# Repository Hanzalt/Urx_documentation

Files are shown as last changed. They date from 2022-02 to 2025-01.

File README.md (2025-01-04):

# Urx_documentation
Welcome to the Urx_documentation! You may be wondering what URX is. URX is first completely open source console. This means that if you want to, you can create it by yourself and completly for FREE. The case is printed on a 3D printer. Electrical components are imported from China and from GM electronics.

To find out more, go to the wiki!

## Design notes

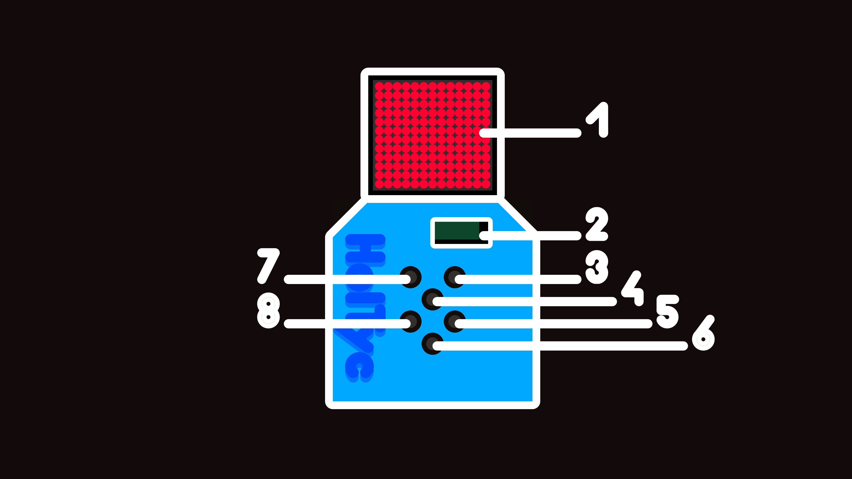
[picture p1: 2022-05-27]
wiki_images/shora.jpg

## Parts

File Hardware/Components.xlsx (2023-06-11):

Komponenty | URL | Poznámka
baterie - 3450 | https://www.gme.cz/akumulator-lithiovy-panasonic-ncr-18650ga-3450 | variace/ lepší baterka
baterie - 2600 | https://www.gme.cz/akumulator-lithiovy-westinghouse-li-ion-18650-2600mah | .
piezo pipac | https://www.gme.cz/kpe-110 | .
arduino nano every | https://store.arduino.cc/products/arduino-nano-every-pack?variant=40830133698711 | .
oled 0,91 inch | https://www.aliexpress.com/item/32798439084.html?spm=a2g0o.order_list.0.0.21ef1802zovYiK | .
zapínací tlačítko | https://www.aliexpress.com/item/4000834984463.html?spm=a2g0o.order_list.0.0.21ef1802vfbqA9 | .
tlačítka | https://www.aliexpress.com/item/33002039235.html?spm=a2g0o.order_list.0.0.21ef1802vfbqA9 | .
nabíjecí modul | https://www.aliexpress.com/item/4001196670805.html?spm=a2g0o.order_list.0.0.21ef1802vfbqA9 | .
display 16x16 | https://www.aliexpress.com/item/1005001288031779.html | .
boost converter | https://www.aliexpress.com/item/4001101711737.html?spm=a2g0o.order_list.0.0.21ef1802zovYiK | .
jst-ph-10-kabely - oboustrana koncovka (bude pouzito) | https://www.aliexpress.com/item/32859226460.html?srcSns=sns_More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 | .
jst-ph-10-kabely - koncovky | https://www.aliexpress.com/item/1005003999865632.html?srcSns=sns_More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 | .
jst-ph-10,5,4-pin | https://www.aliexpress.com/item/4000091077742.html | .
piny - male | https://www.aliexpress.com/item/32724478308.html?spm=a2g0o.order_list.0.0.21ef18029P73HY | .
piny - female Arduino | https://www.aliexpress.com/item/32962790286.html?spm=a2g0o.order_list.0.0.21ef18029P73HY | .
matičky | https://www.sroubyonline.cz/standardni-matice-ocel-bily-zinek-6-din-934 | M3
šroubky | https://www.sroubyonline.cz/spojovaci-material/srouby/zapustne-srouby/din-965-ocel-zinek-bily | M3x8
pcb tlačítka | https://jlcpcb.com/ | .
pcb URX | https://jlcpcb.com/ | .
krabice male | https://www.top-obaly.cz/produkt/kartonove-krabice-postovni#product-199x121x45mm | .
krabice velke | https://www.top-obaly.cz/produkt/kartonove-krabice-postovni#product-235x185x46mm | .
Flo-pak | https://www.top-obaly.cz/produkt/vyplnovy-material-flo-pak#product-green-1 | .
ZIP sáček | https://www.top-obaly.cz/produkt/zip-sacky-classic#product-40x60mm

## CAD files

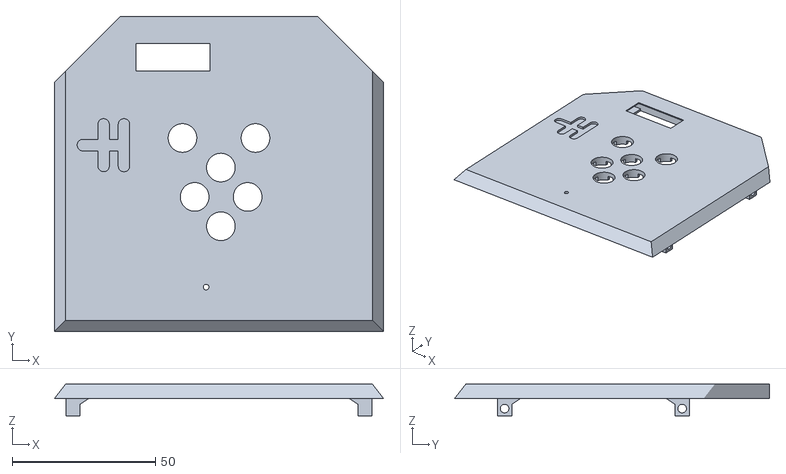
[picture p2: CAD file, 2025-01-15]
Models/Urx_1_top_v4.stl
115.0 x 110.0 x 11.0

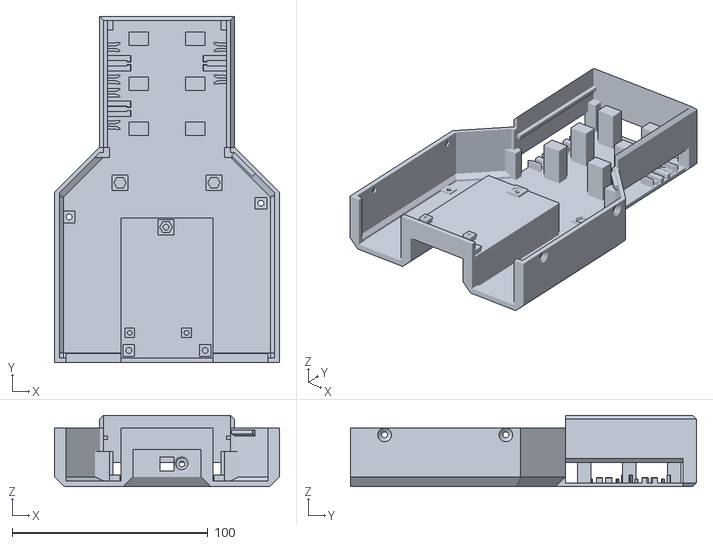
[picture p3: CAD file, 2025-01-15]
Models/Urx_1_bot_v4.stl
115.0 x 177.0 x 36.5

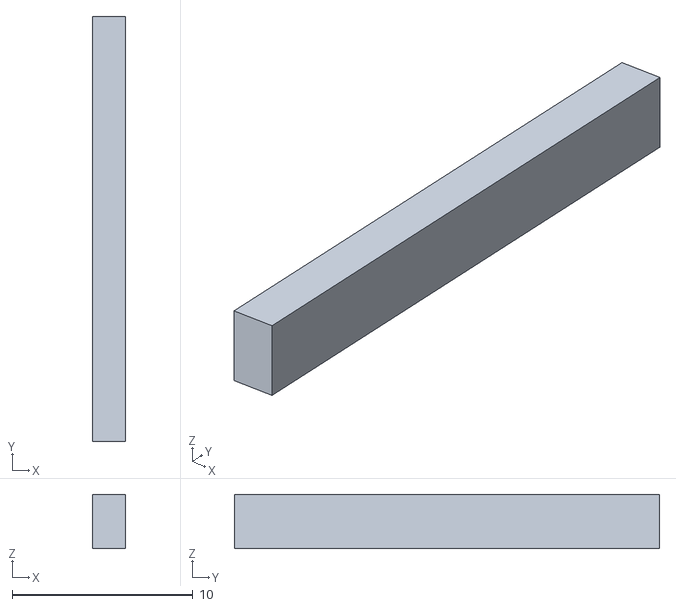
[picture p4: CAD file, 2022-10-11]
Models/Urx_1_tablet_v1.stl
1.80 x 23.5 x 3.00

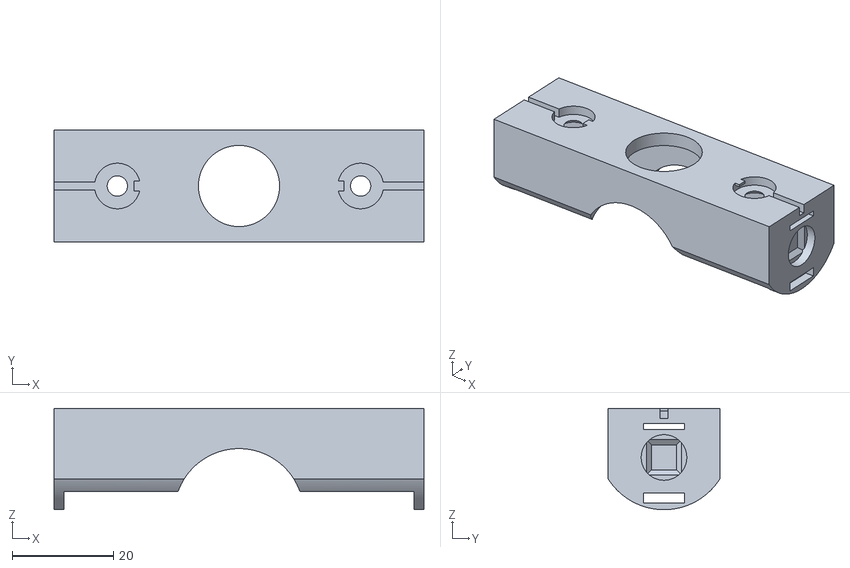
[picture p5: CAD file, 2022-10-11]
Models/Urx_1_battery_holder_v2.stl
73.0 x 22.0 x 20.0

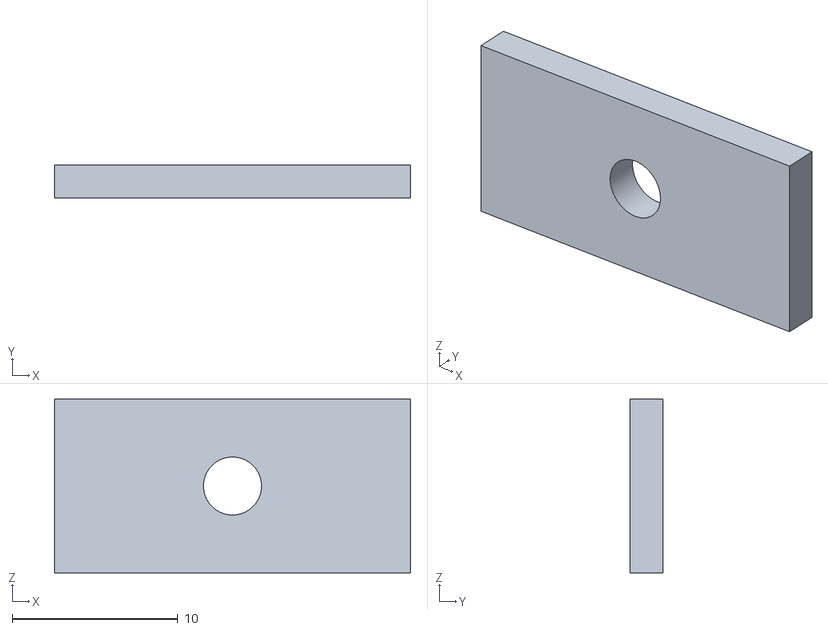
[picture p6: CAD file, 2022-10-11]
Models/Urx_1_power_button_tablet_v1.stl
21.5 x 2.00 x 10.5

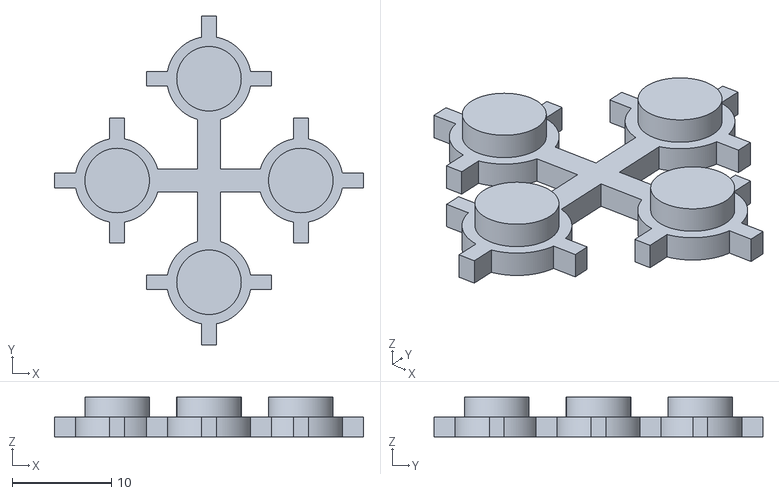
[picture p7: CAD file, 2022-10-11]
Models/Urx_1_buttons_flex_spider_v1.stl
31.1 x 33.1 x 4.00

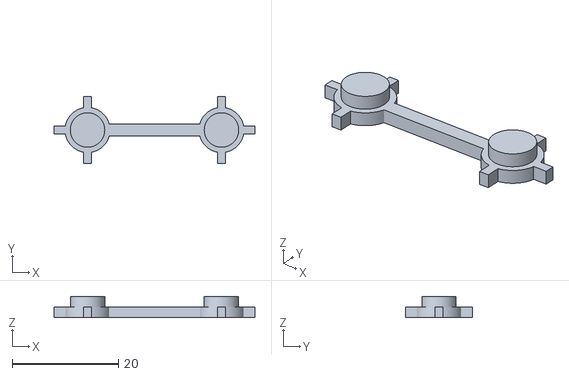
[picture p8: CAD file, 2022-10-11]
Models/Urx_1_buttons_flex_v1.stl
37.9 x 12.6 x 4.00

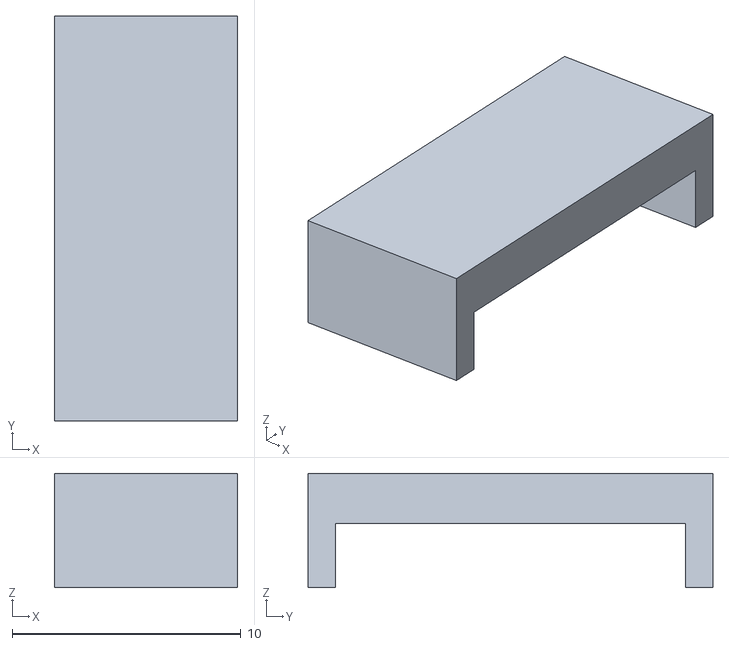
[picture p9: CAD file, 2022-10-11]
Models/Urx_1_secure_tablet_v1.stl
8.00 x 17.7 x 5.00

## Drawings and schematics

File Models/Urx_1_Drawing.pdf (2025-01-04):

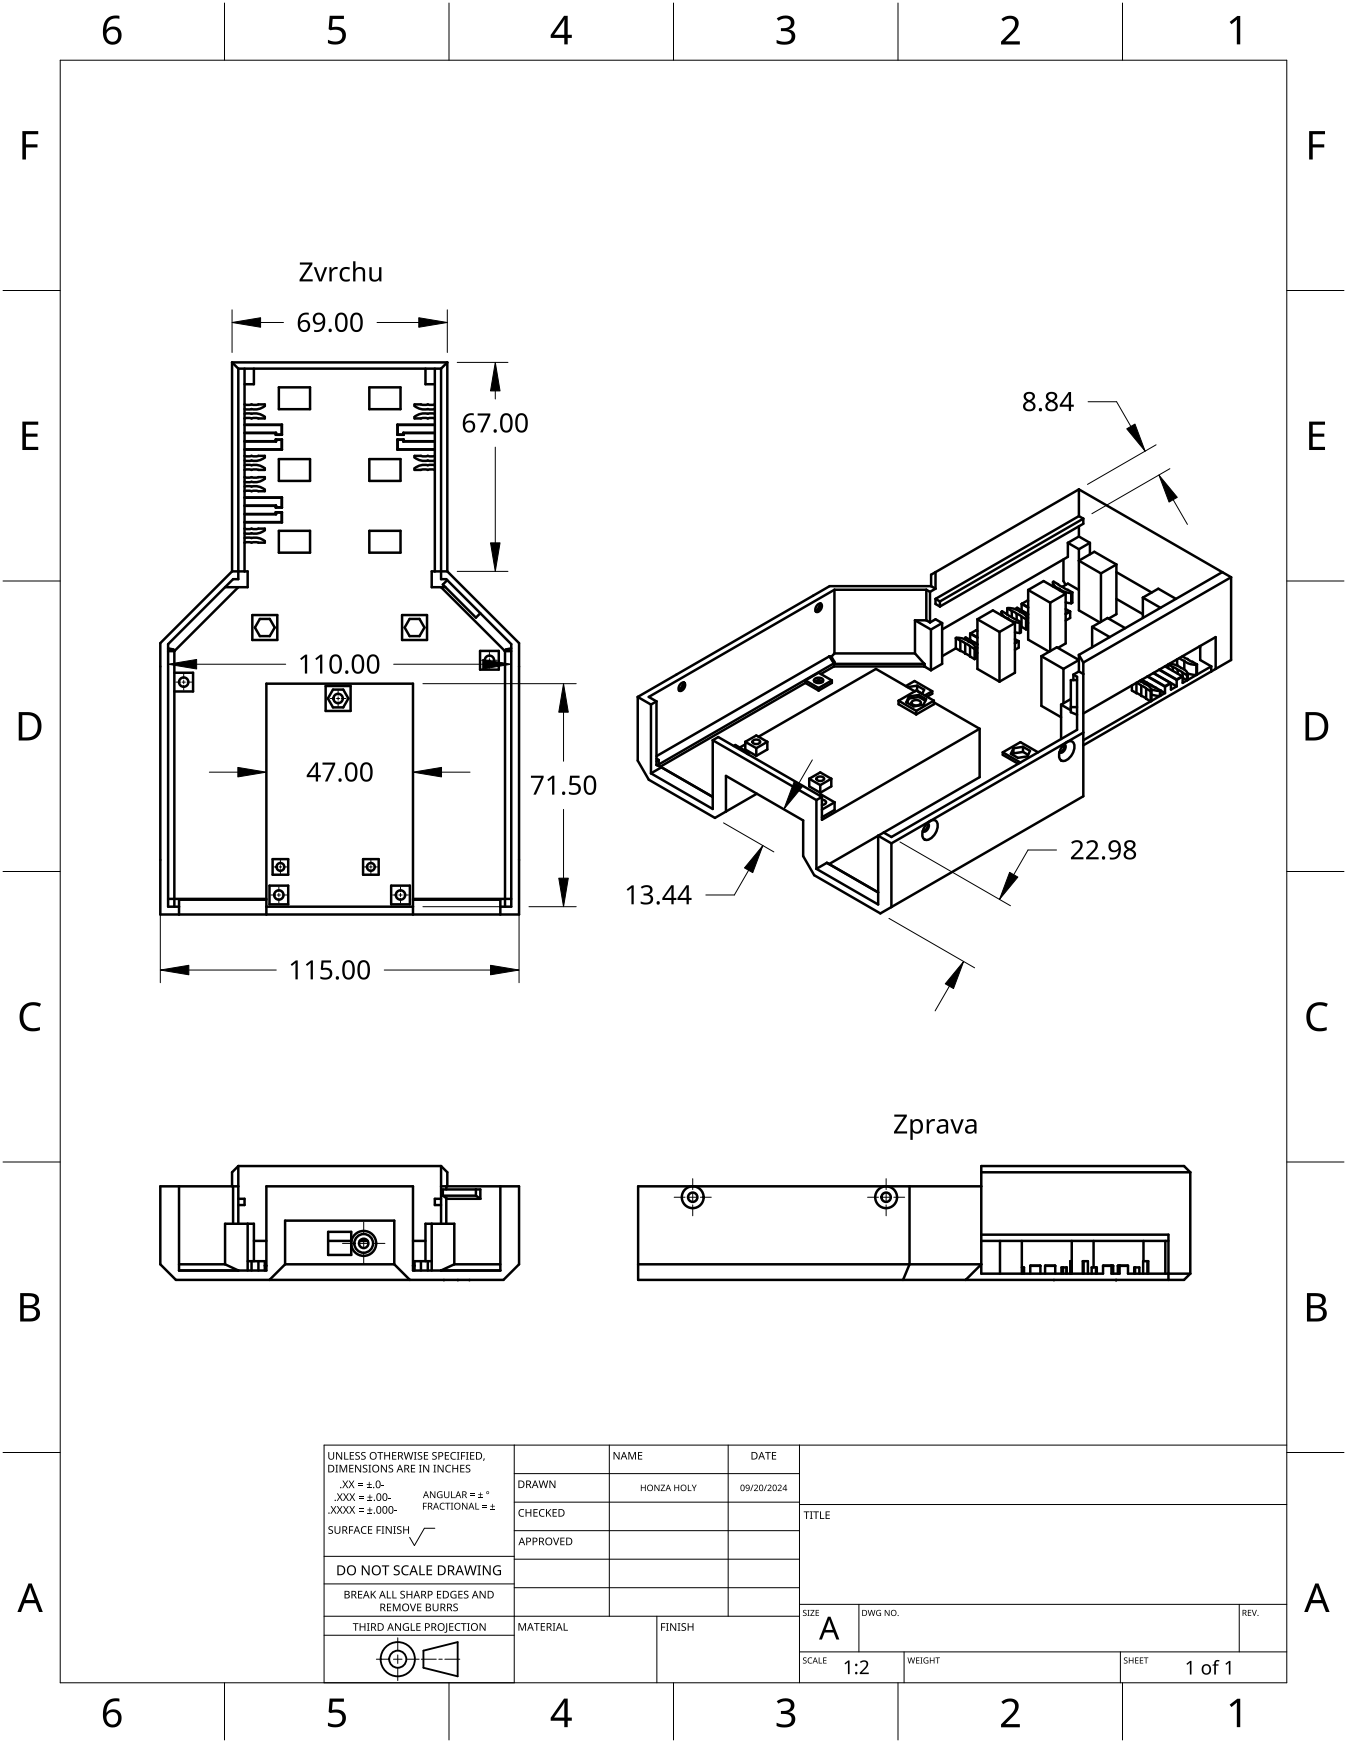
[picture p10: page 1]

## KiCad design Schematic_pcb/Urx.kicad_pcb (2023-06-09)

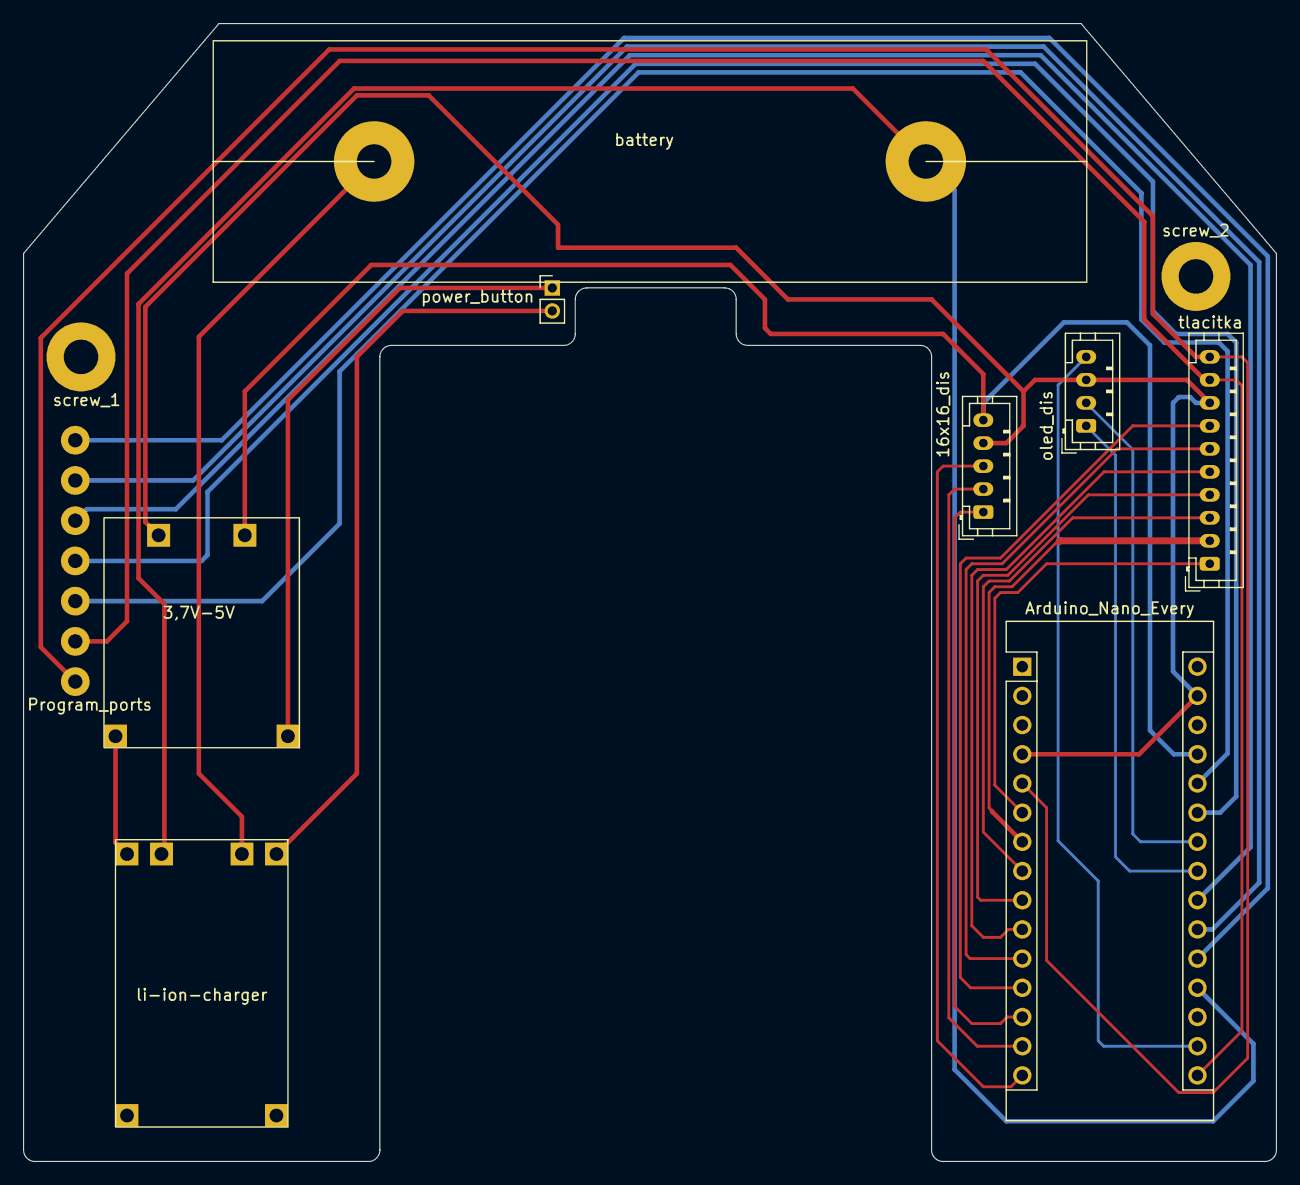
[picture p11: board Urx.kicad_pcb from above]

Board: 2 copper layers, 109.0 x 99.0 mm, 11 parts (0 on the bottom side), 27 nets.

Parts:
3,7V-5V: boost-to-5v
16x16_dis: 5_pin; JST_PH_B5B-PH-K_1x05_P2.00mm_Vertical
Arduino_Nano_Every: Arduino_Nano_Every; Arduino_Nano
Program_ports: 7_pin
battery: battery_li-ion; li-ion_battery
li-ion-charger: li-ion-charger
oled_dis: 4_pin; JST_PH_B4B-PH-K_1x04_P2.00mm_Vertical
power_button: 2_pin; PinHeader_1x02_P2.00mm_Vertical
screw_1, screw_2: MountingHole_3mm_Pad
tlacitka: 10_pin; JST_PH_B10B-PH-K_1x10_P2.00mm_Vertical

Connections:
2: Arduino_Nano_Every.5 (D2), Program_ports.7 (2), tlacitka.10 (n2)
13: Arduino_Nano_Every.16 (SCK), Program_ports.6 (13), tlacitka.9 (n1)
+3V3: Arduino_Nano_Every.17 (3V3), oled_dis.4 (3,3V)
+5V: 3,7V-5V.1 (5V), 16x16_dis.5 (5V), Arduino_Nano_Every.27 (+5V)
ABat: Arduino_Nano_Every.19 (A0), battery.2 (5V), li-ion-charger.1 (B+)
GND: 3,7V-5V.2 (GND), 16x16_dis.4 (gnd), Arduino_Nano_Every.4 (GND), Arduino_Nano_Every.29 (GND), oled_dis.3 (gnd), tlacitka.8 (gnd)
unnamed: 3,7V-5V.3 (IN+), li-ion-charger.5 (OUT+)
unnamed: 3,7V-5V.4 (IN-), power_button.1 (gnd1)
unnamed: 16x16_dis.1 (cs), Arduino_Nano_Every.13 (D10)
unnamed: 16x16_dis.2 (din), Arduino_Nano_Every.14 (MOSI)
unnamed: 16x16_dis.3 (clk), Arduino_Nano_Every.15 (MISO)
unnamed: Arduino_Nano_Every.6 (D3), tlacitka.1 (b)
unnamed: Arduino_Nano_Every.7 (D4), tlacitka.2 (sound)
unnamed: Arduino_Nano_Every.8 (D5), tlacitka.3 (down)
unnamed: Arduino_Nano_Every.9 (D6), tlacitka.4 (left)
unnamed: Arduino_Nano_Every.10 (D7), tlacitka.5 (forward)
unnamed: Arduino_Nano_Every.11 (D8), tlacitka.6 (right)
unnamed: Arduino_Nano_Every.12 (D9), tlacitka.7 (a)
unnamed: Arduino_Nano_Every.20 (A1), Program_ports.1 (A1)
unnamed: Arduino_Nano_Every.21 (A2), Program_ports.2 (A2)
unnamed: Arduino_Nano_Every.22 (A3), Program_ports.3 (A3)
unnamed: Arduino_Nano_Every.23 (SDA/A4), oled_dis.1 (sda)
unnamed: Arduino_Nano_Every.24 (SCL/A5), oled_dis.2 (csk)
unnamed: Arduino_Nano_Every.25 (A6), Program_ports.4 (A6)
unnamed: Arduino_Nano_Every.26 (A7), Program_ports.5 (A7)
unnamed: battery.1 (gnd), li-ion-charger.2 (B-)
unnamed: li-ion-charger.6 (OUT-), power_button.2 (gnd2)

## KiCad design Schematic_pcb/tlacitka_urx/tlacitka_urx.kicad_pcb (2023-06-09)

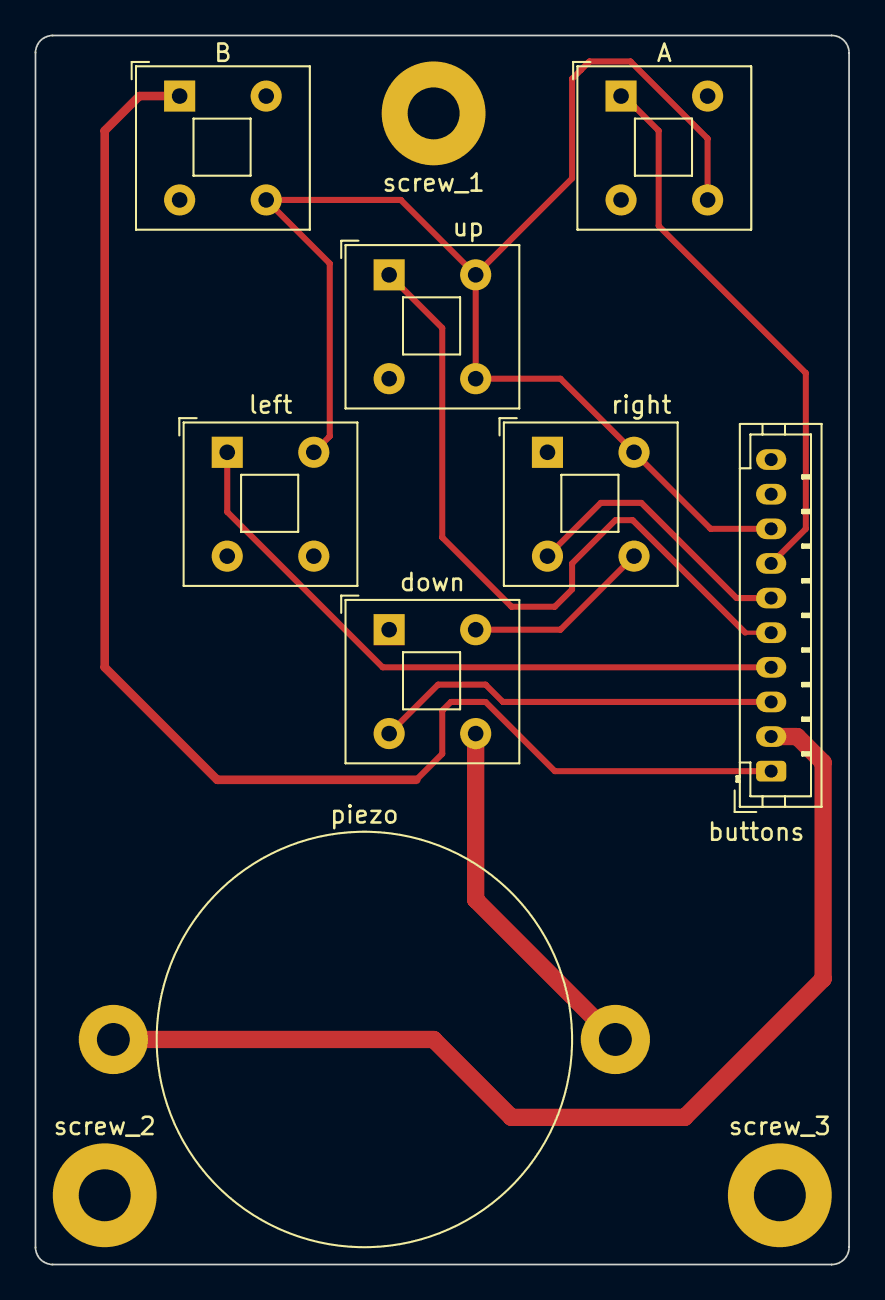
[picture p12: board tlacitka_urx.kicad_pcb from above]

Board: 2 copper layers, 47.0 x 71.0 mm, 11 parts (0 on the bottom side), 10 nets.

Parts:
A: SW_Push_Dual; SW_Push_2P1T_Toggle_CK_PVA1xxH1xxxxxxV2
B: SW_Push_Dual; SW_Push_2P1T_Toggle_CK_PVA1xxH1xxxxxxV2
buttons: 10_pin; JST_PH_B10B-PH-K_1x10_P2.00mm_Vertical
down: SW_Push_Dual; SW_Push_2P1T_Toggle_CK_PVA1xxH1xxxxxxV2
left: SW_Push_Dual; SW_Push_2P1T_Toggle_CK_PVA1xxH1xxxxxxV2
piezo: Piezo_KPEG110
right: SW_Push_Dual; SW_Push_2P1T_Toggle_CK_PVA1xxH1xxxxxxV2
screw_1, screw_2, screw_3: MountingHole_3mm_Pad
up: SW_Push_Dual; SW_Push_2P1T_Toggle_CK_PVA1xxH1xxxxxxV2

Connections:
unnamed: A.1, buttons.7 (a)
unnamed: A.4, B.4, buttons.8 (gnd), left.2, right.2, up.2, up.4
unnamed: B.1, buttons.1 (b)
unnamed: down.2, right.4
unnamed: buttons.3 (down), down.3
unnamed: buttons.4 (left), left.1
unnamed: down.4, piezo.1 (Gnd)
unnamed: buttons.6 (right), right.3
unnamed: buttons.2 (sound), piezo.2
unnamed: buttons.5 (forward), up.1

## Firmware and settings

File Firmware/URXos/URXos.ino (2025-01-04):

#include <Urx.h>
U8G2_SH1106_128X32_VISIONOX_F_HW_I2C u8g2(U8G2_R0, /* reset=*/ U8X8_PIN_NONE);
LedControl lc = LedControl(11, 12, 10, 4);
/*Structure
  SETUP FAZE --------------------------------------------------------------------------- 
  void Setup() - Runs on starting sketch
  
  INPUT FAZE ---------------------------------------------------------------------------
  void blink() - Function for getting inputs from buttons
  void IsButtonPressed() - Function for stopping Urx until someone press any button
  void ActiveButton() - Function for stopping Urx until someone press A button
  
  HELPING FAZE ------------------------------------------------------------------------- 
  Displaying Part ---------
  void ShowBorders(int display) - Function for showing borders on one display
  void displayImage(const word* image, int displaySizeX = 8, int displaySizeY = 0, int display = 0, int offsetX = 0, int offsetY = 0) - Function for displaying images on display
  void displayLed(int row, int col, int state) - Function for turning led on exact X and Y cordinations
  void displayOled(String writing = "") - Function for displaying text on OLED display 
  void displayClear() - Function for clearing big display
  
  Snake Part ---------
  void GenerateFood() - Snake function for generating food
  void SettingGameSnake() - Setting starting conditions for Snake like length and speed of snake
  void Warp() - Take care for warping through walls
  
  Galaxian Part ---------
  void ShootG(int canon) - Function for shooting in Galaxian
  void EnemyG(int passage) - Function for spawning enemys in Galaxian
  void SettingGameGalaxian() - Function for setting Galaxian
  
  DanceMan Part ---------
  void SettingGameDanceMan() - Setting starting conditions for DanceMan like speed song etc.
  
  Generic Part ---------
  void PlaySound(int sound, int i = 0) - Function for playing sound
  void write2EEPROM(int address, int number) - Function for writing 2byte int to EEPROM
  int read2EEPROM(int address) - Function for reading EEPROM from 2byte space
  void DrawMenu() - Function for drawing app menu
  void SettingSetting() - Function for setting setting
  void SleepModeUpdate() - Function for taking care of sleep mode
  
  GAME FAZE ----------------------------------------------------------------------------
  void Menu() - Function that takes care of menu
  void GameOver() - Function for managing gamestate gameover
  void SnakeMenu() - Function that takes care for snake menu that has settings
  void Snake() - Main function for game Snake
  
  LOOP FAZE ----------------------------------------------------------------------------
  void Loop() - Runs forever
*/

/****************************************************************/
//Snake
/****************************************************************/

//Version
const String versionUrxOS = "0.8.3";
//Food position
int foodX = 0;
int foodY = 0;
//Super food position
int foodXSuper = 0;
int foodYSuper = 0;
//Delay in game is overrided when function SettingGameSnake is called
float delayTime = 300;
//GameState for setting menu - 0, gameover - 1, game - snake - 2, game - danceMan = 3, intensity - 4, difficulty - 41, settings - 5, galaxian - 6
int gameState = 0;
//Variables that is used in showing borders to apps
int whichIconShowed = 0;
int whichMedal = 0;
//Time variables
unsigned long allTime = 0;
unsigned long lastTime = 0;
unsigned long lastTime2 = 0;
unsigned long soundTime = 0;
unsigned long soundLastTime = 0;
unsigned long lastDebounceTime = 0;
const int debounceDelay = 100;
int soundDelay = 0;
int soundDelay1 = 0;
//Buttons variables
const int forward = 7;//7,8
const int right = 8;//8,6
const int left = 6;//6,7
const int down = 5;//5,5
const int a = 9;
const int soundPin = 4;
const int b = 3;
//Battery analog pin
const int battery = A0;
//Constant variables that are use when SettingGameSnake is called
const int delayTimeConst = 230;
const int bodyLengthConst = 3;
//Variables for turning one row ON and OFF
const int allLedTurnOn = 0b11111111;
const int allLedTurnOff = 0b00000000;
//EEPROM addresses
const int addressSound = 1;
const int addressIntensity = 2;
const int addressDifficulty = 3;
const int addressSnake1 = 4;
const int addressSnake2 = 6;
const int addressGalaxian1 = 8;
const int addressGalaxian2 = 10;
//Movement variables
volatile int x = 0;
volatile int y = 0;
volatile int active = 0;
//Helping movement variables
int shiftedX = 7;
int shiftedY = 7;
volatile int allwaysX = 0;
volatile int allwaysY = 0;
//Variable for length of snake
int bodyLength = 3;
//Timer variable
int timer = 0;
//Variable for moving enemy
int moveEnemy1 = 0;
//Variable for wave system
int wave = 0;
//Variable to set modes
int mode = 0;
//Variable that is used to count what note to play
int noteCounter = 0;
//Variable use to store points
int points = 6;
//Variable is for every use. If you need to have some helping variable then this is it.
int helpingVariable = 0;
//Variable for setting difficulty
int difficulty = 0;
//Variable for setting intensity
int intensity = 0;
//Variables for turning congrats song
byte congrats = 0;
bool congratsState = true;
//Variable for knowing if game is ON
bool isGameOn = 0;
//Variable that is used in sound making
bool soundState = true;
//Variable to turn on
bool menuFirstWalkThrough = true;
//Variable to draw apps
bool goThrough = true;
//Variable to know if you need to show staring led
bool startingLedOn = true;
bool load = true;
bool lastState = true;
//Variables for sleep mode
const int long sleepModeActivationDelay = 300000; //in milliseconds
unsigned long timeOfLastInput = 0;

const int melodyGalaxian[] PROGMEM = {

  // Bloody Tears, from Castlevania II
  // Arranged by Bobby Lee. THe flute part was used
  // https://musescore.com/user/263171/scores/883296

  //B-flat major Bb Eb
  REST, 4, NOTE_G5, 4,
  NOTE_A5, 4, NOTE_AS5, 4,
  NOTE_A5, 4, NOTE_F5, 4,
  NOTE_A5, 4, NOTE_G5, 4,
  REST, 4, NOTE_G5, 4,
  NOTE_A5, 4, NOTE_AS5, 4,
  NOTE_C6, 4, NOTE_AS5, 4,

  NOTE_A5, 4, NOTE_G5, 4, //8
  REST, 4, NOTE_G5, 4,
  NOTE_A5, 4, NOTE_AS5, 4,
  NOTE_A5, 4, NOTE_F5, 4,
  NOTE_A5, 4, NOTE_G5, 4,
  NOTE_D6, 4, REST, 8, NOTE_C6, 8,
  REST, 4, NOTE_AS5, 4,

  NOTE_A5, 4, NOTE_AS5, 8, NOTE_C6, 8, //15
  NOTE_F6, 8, REST, 8, REST, 4,
  NOTE_G5, 16, NOTE_D5, 16, NOTE_D6, 16, NOTE_D5, 16, NOTE_C6, 16, NOTE_D5, 16, NOTE_AS5, 16, NOTE_D5, 16,
  NOTE_A5, 16, NOTE_D5, 16, NOTE_AS5, 16, NOTE_D5, 16, NOTE_A5, 16, NOTE_D5, 16, NOTE_G5, 16, NOTE_D5, 16,
  NOTE_A5, 16, NOTE_D5, 16, NOTE_AS5, 16, NOTE_D5, 16, NOTE_C6, 16, NOTE_D5, 16, NOTE_AS5, 16, NOTE_D5, 16,

  NOTE_A5, 16, NOTE_D5, 16, NOTE_F5, 16, NOTE_D5, 16, NOTE_A5, 16, NOTE_D5, 16, NOTE_G5, 16, NOTE_D5, 16, //20
  NOTE_G5, 16, NOTE_D5, 16, NOTE_D6, 16, NOTE_D5, 16, NOTE_C6, 16, NOTE_D5, 16, NOTE_AS5, 16, NOTE_D5, 16,
  NOTE_A5, 16, NOTE_D5, 16, NOTE_AS5, 16, NOTE_D5, 16, NOTE_A5, 16, NOTE_D5, 16, NOTE_AS5, 16, NOTE_D5, 16,
  NOTE_A5, 16, NOTE_D5, 16, NOTE_AS5, 16, NOTE_D5, 16, NOTE_C6, 16, NOTE_D5, 16, NOTE_AS5, 16, NOTE_D5, 16,
  NOTE_A5, 16, NOTE_D5, 16, NOTE_F5, 16, NOTE_D5, 16, NOTE_A5, 16, NOTE_D5, 16, NOTE_G5, 16, NOTE_D5, 16,

  NOTE_G5, 16, NOTE_D5, 16, NOTE_D6, 16, NOTE_D5, 16, NOTE_C6, 16, NOTE_D5, 16, NOTE_AS5, 16, NOTE_D5, 16, //25
  NOTE_A5, 16, NOTE_D5, 16, NOTE_AS5, 16, NOTE_D5, 16, NOTE_A5, 16, NOTE_D5, 16, NOTE_G5, 16, NOTE_D5, 16,
  NOTE_A5, 16, NOTE_D5, 16, NOTE_AS5, 16, NOTE_D5, 16, NOTE_C6, 16, NOTE_D5, 16, NOTE_AS5, 16, NOTE_D5, 16,
  NOTE_A5, 16, NOTE_D5, 16, NOTE_F5, 16, NOTE_D5, 16, NOTE_A5, 16, NOTE_D5, 16, NOTE_G5, 16, NOTE_D5, 16,
  NOTE_AS5, 16, NOTE_D5, 16, NOTE_D6, 16, NOTE_D5, 16, NOTE_C6, 16, NOTE_D5, 16, NOTE_AS5, 16, NOTE_D5, 16,

  NOTE_A5, 16, NOTE_D5, 16, NOTE_AS5, 16, NOTE_D5, 16, NOTE_A5, 16, NOTE_D5, 16, NOTE_G5, 16, NOTE_D5, 16,
  NOTE_A5, 16, NOTE_D5, 16, NOTE_AS5, 16, NOTE_D5, 16, NOTE_C6, 16, NOTE_D5, 16, NOTE_AS5, 16, NOTE_D5, 16,
  NOTE_A5, 16, NOTE_D5, 16, NOTE_F5, 16, NOTE_D5, 16, NOTE_A5, 16, NOTE_D5, 16, NOTE_G5, 16, NOTE_D5, 16,
  NOTE_C6, 16, NOTE_C6, 16, NOTE_F6, 16, NOTE_D6, 8, REST, 16, REST, 8,
  REST, 4, NOTE_C6, 16, NOTE_AS5, 16,

  NOTE_C6, -8,  NOTE_F6, -8, NOTE_D6, -4, //35
  NOTE_C6, 8, NOTE_AS5, 8,
  NOTE_C6, 8, NOTE_F6, 16, NOTE_D6, 8, REST, 16, REST, 8,
  REST, 4, NOTE_C6, 8, NOTE_D6, 8,
  NOTE_DS6, -8, NOTE_F6, -8,

  NOTE_D6, -8, REST, 16, NOTE_DS6, 8, REST, 8, //40
  NOTE_C6, 8, NOTE_F6, 16, NOTE_D6, 8, REST, 16, REST, 8,
  REST, 4, NOTE_C6, 8, NOTE_AS5, 8,
  NOTE_C6, -8,  NOTE_F6, -8, NOTE_D6, -4,
  NOTE_C6, 8, NOTE_AS5, 8,

  NOTE_C6, 8, NOTE_F6, 16, NOTE_D6, 8, REST, 16, REST, 8, //45
  REST, 4, NOTE_C6, 8, NOTE_D6, 8,
  NOTE_DS6, -8, NOTE_F6, -8,
  NOTE_D5, 8, NOTE_FS5, 8, NOTE_F5, 8, NOTE_A5, 8,
  NOTE_A5, -8, NOTE_G5, -4,

  NOTE_A5, -8, NOTE_G5, -4, //50
  NOTE_A5, -8, NOTE_G5, -4,
  NOTE_AS5, 8, NOTE_A5, 8, NOTE_G5, 8, NOTE_F5, 8,
  NOTE_A5, -8, NOTE_G5, -8, NOTE_D5, 8,
  NOTE_A5, -8, NOTE_G5, -8, NOTE_D5, 8,
  NOTE_A5, -8, NOTE_G5, -8, NOTE_D5, 8,

  NOTE_AS5, 4, NOTE_C6, 4, NOTE_A5, 4, NOTE_AS5, 4,
  NOTE_G5, 16, NOTE_D5, 16, NOTE_D6, 16, NOTE_D5, 16, NOTE_C6, 16, NOTE_D5, 16, NOTE_AS5, 16, NOTE_D5, 16, //56 //r
  NOTE_A5, 16, NOTE_D5, 16, NOTE_AS5, 16, NOTE_D5, 16, NOTE_A5, 16, NOTE_D5, 16, NOTE_G5, 16, NOTE_D5, 16,
  NOTE_A5, 16, NOTE_D5, 16, NOTE_AS5, 16, NOTE_D5, 16, NOTE_C6, 16, NOTE_D5, 16, NOTE_AS5, 16, NOTE_D5, 16,
  NOTE_A5, 16, NOTE_D5, 16, NOTE_F5, 16, NOTE_D5, 16, NOTE_A5, 16, NOTE_D5, 16, NOTE_G5, 16, NOTE_D5, 16,

  NOTE_G5, 16, NOTE_D5, 16, NOTE_D6, 16, NOTE_D5, 16, NOTE_C6, 16, NOTE_D5, 16, NOTE_AS5, 16, NOTE_D5, 16, //61
  NOTE_A5, 16, NOTE_D5, 16, NOTE_AS5, 16, NOTE_D5, 16, NOTE_A5, 16, NOTE_D5, 16, NOTE_AS5, 16, NOTE_D5, 16,
  NOTE_A5, 16, NOTE_D5, 16, NOTE_AS5, 16, NOTE_D5, 16, NOTE_C6, 16, NOTE_D5, 16, NOTE_AS5, 16, NOTE_D5, 16,
  NOTE_A5, 16, NOTE_D5, 16, NOTE_F5, 16, NOTE_D5, 16, NOTE_A5, 16, NOTE_D5, 16, NOTE_G5, 16, NOTE_D5, 16,
  NOTE_G5, 16, NOTE_D5, 16, NOTE_D6, 16, NOTE_D5, 16, NOTE_C6, 16, NOTE_D5, 16, NOTE_AS5, 16, NOTE_D5, 16,

  NOTE_A5, 16, NOTE_D5, 16, NOTE_AS5, 16, NOTE_D5, 16, NOTE_A5, 16, NOTE_D5, 16, NOTE_G5, 16, NOTE_D5, 16, //66
  NOTE_A5, 16, NOTE_D5, 16, NOTE_AS5, 16, NOTE_D5, 16, NOTE_C6, 16, NOTE_D5, 16, NOTE_AS5, 16, NOTE_D5, 16,
  NOTE_A5, 16, NOTE_D5, 16, NOTE_F5, 16, NOTE_D5, 16, NOTE_A5, 16, NOTE_D5, 16, NOTE_G5, 16, NOTE_D5, 16,
  NOTE_AS5, 16, NOTE_D5, 16, NOTE_D6, 16, NOTE_D5, 16, NOTE_C6, 16, NOTE_D5, 16, NOTE_AS5, 16, NOTE_D5, 16,
  NOTE_A5, 16, NOTE_D5, 16, NOTE_AS5, 16, NOTE_D5, 16, NOTE_A5, 16, NOTE_D5, 16, NOTE_G5, 16, NOTE_D5, 16,

  NOTE_A5, 16, NOTE_D5, 16, NOTE_AS5, 16, NOTE_D5, 16, NOTE_C6, 16, NOTE_D5, 16, NOTE_AS5, 16, NOTE_D5, 16, //71 //
  NOTE_A5, 16, NOTE_D5, 16, NOTE_F5, 16, NOTE_D5, 16, NOTE_A5, 8, NOTE_G5, 32, NOTE_A5, 32, NOTE_AS5, 32, NOTE_C6, 32,
  NOTE_D6, 16, NOTE_G5, 16, NOTE_AS5, 16, NOTE_G5, 16, NOTE_C6, 16, NOTE_G5, 16, NOTE_D6, 16, NOTE_G5, 16,
  NOTE_C6, 16, NOTE_G5, 16, NOTE_A5, 16, NOTE_G5, 16, NOTE_F6, 16, NOTE_G5, 16, NOTE_D6, 16, NOTE_DS5, 16,
  NOTE_D6, 4, REST, 4,

  NOTE_C5, 8, REST, 8, NOTE_A4, -16, NOTE_AS4, -16, NOTE_C5, 16, //76
  NOTE_D6, 16, NOTE_G4, 16, NOTE_AS4, 16, NOTE_G4, 16, NOTE_C5, 16, NOTE_G4, 16, NOTE_D6, 16, NOTE_G4, 16,
  NOTE_C6, 16, NOTE_F4, 16, NOTE_A4, 16, NOTE_F4, 16, NOTE_F5, 16, NOTE_F4, 16, NOTE_D6, 16, NOTE_DS4, 16,
  NOTE_D6, 16, REST, 8, NOTE_E4, 16, NOTE_F4, 16,

  //change of key B Major A# C# D# F# G#
  NOTE_GS4, 8, REST, 8, NOTE_AS4, 8, REST, 8,

  NOTE_DS5, 16, NOTE_GS4, 16, NOTE_B4, 16, NOTE_GS4, 16, NOTE_CS5, 16, NOTE_GS4, 16, NOTE_DS5, 16, NOTE_GS4, 16, //81
  NOTE_CS5, 16, NOTE_FS4, 16, NOTE_AS4, 16, NOTE_FS4, 16, NOTE_FS5, 16, NOTE_FS4, 16, NOTE_DS5, 16, NOTE_E5, 16,
  NOTE_D5, 4, REST, 4,
  NOTE_CS5, 8, REST, 8, NOTE_AS4, -16,  NOTE_B4, -16, NOTE_CS5, 16,
  NOTE_DS5, 16, NOTE_GS4, 16, NOTE_B4, 16, NOTE_GS4, 16, NOTE_CS5, 16, NOTE_GS4, 16, NOTE_DS5, 16, NOTE_GS4, 16,

  NOTE_CS5, 16, NOTE_FS4, 16, NOTE_AS4, 16, NOTE_FS4, 16, NOTE_FS5, 16, NOTE_FS4, 16, NOTE_DS5, 16, NOTE_E5, 16,
  NOTE_DS5, 4, REST, 8, NOTE_DS5, 16,  NOTE_E5, 16,
  NOTE_FS5, 16, NOTE_CS5, 16, NOTE_E5, 16, NOTE_CS4, 16, NOTE_DS5, 16, NOTE_E5, 16, NOTE_G5, 16, NOTE_AS5, 16,
  NOTE_GS5, 16, NOTE_DS5, 16, NOTE_DS6, 16, NOTE_DS5, 16, NOTE_CS6, 16, NOTE_DS5, 16, NOTE_B5, 16, NOTE_DS5, 16,

  NOTE_AS5, 16, NOTE_DS5, 16, NOTE_B5, 16, NOTE_DS5, 16, NOTE_AS5, 16, NOTE_DS5, 16, NOTE_GS5, 16, NOTE_DS5, 16, //90
  NOTE_AS5, 16, NOTE_DS5, 16, NOTE_B5, 16, NOTE_DS5, 16, NOTE_CS6, 16, NOTE_DS5, 16, NOTE_B5, 16, NOTE_DS5, 16,
  NOTE_AS5, 16, NOTE_DS5, 16, NOTE_FS5, 16, NOTE_DS5, 16, NOTE_AS5, 16, NOTE_DS5, 16, NOTE_GS5, 16, NOTE_DS5, 16,
  NOTE_GS5, 16, NOTE_DS5, 16, NOTE_DS6, 16, NOTE_DS5, 16, NOTE_CS6, 16, NOTE_DS5, 16, NOTE_B5, 16, NOTE_DS5, 16,

  NOTE_AS5, 16, NOTE_DS5, 16, NOTE_B5, 16, NOTE_DS5, 16, NOTE_AS5, 16, NOTE_DS5, 16, NOTE_GS5, 16, NOTE_DS5, 16,//94
  NOTE_AS5, 16, NOTE_DS5, 16, NOTE_B5, 16, NOTE_DS5, 16, NOTE_CS6, 16, NOTE_DS5, 16, NOTE_B5, 16, NOTE_DS5, 16,
  NOTE_AS5, 16, NOTE_DS5, 16, NOTE_FS5, 16, NOTE_DS5, 16, NOTE_AS5, 16, NOTE_DS5, 16, NOTE_GS5, 16, NOTE_DS5, 16,
  NOTE_GS5, 16, NOTE_DS5, 16, NOTE_DS6, 16, NOTE_DS5, 16, NOTE_CS6, 16, NOTE_DS5, 16, NOTE_B5, 16, NOTE_DS5, 16,

  NOTE_AS5, 16, NOTE_DS5, 16, NOTE_B5, 16, NOTE_DS5, 16, NOTE_AS5, 16, NOTE_DS5, 16, NOTE_GS5, 16, NOTE_DS5, 16,//98
  NOTE_AS5, 16, NOTE_DS5, 16, NOTE_B5, 16, NOTE_DS5, 16, NOTE_CS6, 16, NOTE_DS5, 16, NOTE_B5, 16, NOTE_DS5, 16,
  NOTE_AS5, 16, NOTE_DS5, 16, NOTE_FS5, 16, NOTE_DS5, 16, NOTE_AS5, 16, NOTE_DS5, 16, NOTE_GS5, 16, NOTE_DS5, 16,
  NOTE_GS5, 16, NOTE_DS5, 16, NOTE_DS6, 16, NOTE_DS5, 16, NOTE_CS6, 16, NOTE_DS5, 16, NOTE_B5, 16, NOTE_DS5, 16,

  NOTE_AS5, 16, NOTE_DS5, 16, NOTE_B5, 16, NOTE_DS5, 16, NOTE_AS5, 16, NOTE_DS5, 16, NOTE_GS5, 16, NOTE_DS5, 16,//102
  NOTE_AS5, 16, NOTE_DS5, 16, NOTE_B5, 16, NOTE_DS5, 16, NOTE_CS6, 16, NOTE_DS5, 16, NOTE_B5, 16, NOTE_DS5, 16,
  NOTE_AS5, 16, NOTE_DS5, 16, NOTE_FS5, 16, NOTE_DS5, 16, NOTE_AS5, 16, NOTE_DS5, 16, NOTE_GS5, 16, NOTE_DS5, 16,

  NOTE_CS6, 8, NOTE_FS6, 16, NOTE_DS6, 8, REST, 16, REST, 8, //107
  REST, 4, NOTE_CS6, 8, NOTE_B5, 8,
  NOTE_CS6, -8, NOTE_FS6, -8, NOTE_DS6, -4,
  NOTE_CS6, 8, NOTE_B5, 8,
  NOTE_CS6, 8, NOTE_FS6, 16, NOTE_DS6, 8, REST, 16, REST, 8,
  REST, 4, NOTE_CS6, 8, NOTE_B5, 8,
  NOTE_E6, -8, NOTE_F6, -8,

  NOTE_DS6, -8, REST, 16, NOTE_E6, 8, REST, 16, REST, 16, //112
  NOTE_CS6, 8, NOTE_FS6, 16, NOTE_DS6, 8, REST, 16, REST, 8,
  REST, 4, NOTE_CS6, 8, NOTE_B5, 8,
  NOTE_CS6, -8, NOTE_FS6, -8, NOTE_DS6, -4,
  NOTE_CS6, 8, NOTE_B5, 8,

  NOTE_CS6, 8, NOTE_FS6, 16, NOTE_DS6, 8, REST, 16, REST, 8, //117
  REST, 4, NOTE_CS5, 8, NOTE_DS5, 8,
  NOTE_E5, -8, NOTE_F5, -8,
  NOTE_DS5, 8, NOTE_G5, 8, NOTE_GS5, 8, NOTE_AS5, 8,
  NOTE_AS5, -8, NOTE_GS5, -8,

  NOTE_AS5, -8, NOTE_GS5, -8,//122
  NOTE_AS5, -8, NOTE_GS5, -8,
  NOTE_B6, 8, NOTE_AS5, 8, NOTE_GS5, 8, NOTE_FS5, 8,
  NOTE_AS5, -8, NOTE_GS6, -8, NOTE_DS5, 8,
  NOTE_AS5, -8, NOTE_GS6, -8, NOTE_DS5, 8,
  NOTE_AS5, -8, NOTE_GS6, -8, NOTE_DS5, 8,

  NOTE_B5, 8, NOTE_CS6, 8, NOTE_AS5, 8, NOTE_B5, 8, //128
  NOTE_GS5, 8, REST, 8, REST, 16

};
const int melodyCat[] PROGMEM = {

  // Keyboard cat
  // Score available at https://musescore.com/user/142788/scores/147371

  NOTE_C4, 4, NOTE_E4, 4, NOTE_G4, 4, NOTE_E4, 4,
  NOTE_C4, 4, NOTE_E4, 8, NOTE_G4, -4, NOTE_E4, 4,
  NOTE_A3, 4, NOTE_C4, 4, NOTE_E4, 4, NOTE_C4, 4,
  NOTE_A3, 4, NOTE_C4, 8, NOTE_E4, -4, NOTE_C4, 4,
  NOTE_G3, 4, NOTE_B3, 4, NOTE_D4, 4, NOTE_B3, 4,
  NOTE_G3, 4, NOTE_B3, 8, NOTE_D4, -4, NOTE_B3, 4,

  NOTE_G3, 4, NOTE_G3, 8, NOTE_G3, -4, NOTE_G3, 8, NOTE_G3, 4,
  NOTE_G3, 4, NOTE_G3, 4, NOTE_G3, 8, NOTE_G3, 4,
  NOTE_C4, 4, NOTE_E4, 4, NOTE_G4, 4, NOTE_E4, 4,
  NOTE_C4, 4, NOTE_E4, 8, NOTE_G4, -4, NOTE_E4, 4,
  NOTE_A3, 4, NOTE_C4, 4, NOTE_E4, 4, NOTE_C4, 4,
  NOTE_A3, 4, NOTE_C4, 8, NOTE_E4, -4, NOTE_C4, 4,
  NOTE_G3, 4, NOTE_B3, 4, NOTE_D4, 4, NOTE_B3, 4,
  NOTE_G3, 4, NOTE_B3, 8, NOTE_D4, -4, NOTE_B3, 4,

  NOTE_G3, -1,

};
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
void loop() {
  //Turning Led_builtin on if button is pressed for debugging
  //digitalWrite(LED_BUILTIN, digitalRead(forward) | digitalRead(down) | digitalRead(right) | digitalRead(left));
  //Turning snake ON
  soundTime = millis();
  if (gameState == -1) {
    displayClear();
  } else if (gameState == 2) {
    Snake();
  } else if (gameState == 0) {
    Menu(menuFirstWalkThrough, goThrough);
    menuFirstWalkThrough = false;
    goThrough = false;
  } else if (gameState == 3) {
    DanceMan();
  } else if (gameState == 4) {
    InfoFun(true);
  } else if (gameState == 41) {
    InfoFun(false);
  } else if (gameState == 5) {
    NastaveniHer();
  } else if (gameState == 6) {
    GalaxianGame();
  }
  if (soundTime - soundLastTime >= soundDelay and soundDelay1 == 0) {
    noTone(soundPin);
    soundLastTime = soundTime;
    if (soundDelay == 200 and noteCounter == 0) {
      if (congrats > 3) {
        soundDelay = 0;
      } else {
        congrats += 1;
        congratsState = true;
      }
    } else if (soundDelay == 150) {
      tone(soundPin, 200);
      soundDelay = 151;
    } else if (soundDelay == 151) {
      tone(soundPin, 360);
      soundDelay = 0;
    } else {
      soundDelay = 0;
    }
  }
  if (soundTime - soundLastTime >= soundDelay1 and soundDelay == 0) {
    noTone(soundPin);
    soundLastTime = soundTime;
    soundDelay1 = 0;
  }

  SleepModeUpdate();
}

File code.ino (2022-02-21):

//(Snad posledni verze) Po druhym vyhorenim jsme se rozhodl udelat algoritmus smesi for cyklu(verze jedna) a smerem zapinani a zapinani(verze dva) JDU NA TO
//OLED displey https://s.click.aliexpress.com/e/_APw28Y
#include "LedControl.h"
#include <EEPROM.h>
LedControl lc = LedControl(11, 12, 10, 4);
/*Structure 
SETUP FAZE -------------------
void Setup() - Runs on starting sketch
INPUT FAZE -------------------
void Button() - Function is for getting inputs from buttons
GAME FAZE --------------------
void Menu() - Function that takes care of menu
void GameOver() - Function for managing gamestate gameover
void SnakeMenu() - Function that takes care for snake menu that has settings   
void Snake() - Main function for game Snake
HELPING FAZE -----------------
void SettingGameSnake() - Setting starting conditions like length and speed of snake
void Warp() - Take care for warping through walls
void TurningLedArray() - Function for turning leds in game on/off
void ShowText() - Function for turning text on/off
void ShowOneDisplay() - Function for managing one display
void ShowBorders() - Function for showing borders on one display
void GenerateFood() - Function for setting random food position 
int IsButtonPressed() - Function for stoping the game untile some button is pressed and then return number corresponding to the direction
void PlaySound() - Function for playing chosen sound
LOOP FAZE --------------------
void Loop() - Runs every 1/100s or every 10 ms
*/

/****************************************************************/
//Snake
/****************************************************************/

//Array for remembering the hole pixel matrix
int Array[16][16] = {{ 0, 0, 0, 0, 0, 0, 0, 0, 0, 0, 0, 0, 0, 0, 0, 0 },
                    {  0, 0, 0, 0, 0, 0, 0, 0, 0, 0, 0, 0, 0, 0, 0, 0 },
                    {  0, 0, 0, 0, 0, 0, 0, 0, 0, 0, 0, 0, 0, 0, 0, 0 },
                    {  0, 0, 0, 0, 0, 0, 0, 0, 0, 0, 0, 0, 0, 0, 0, 0 },
                    {  0, 0, 0, 0, 0, 0, 0, 0, 0, 0, 0, 0, 0, 0, 0, 0 },
                    {  0, 0, 0, 0, 0, 0, 0, 0, 0, 0, 0, 0, 0, 0, 0, 0 },
                    {  0, 0, 0, 0, 0, 0, 0, 0, 0, 0, 0, 0, 0, 0, 0, 0 },
                    {  0, 0, 0, 0, 0, 0, 0, 0, 0, 0, 0, 0, 0, 0, 0, 0 },
                    {  0, 0, 0, 0, 0, 0, 0, 0, 0, 0, 0, 0, 0, 0, 0, 0 },
                    {  0, 0, 0, 0, 0, 0, 0, 0, 0, 0, 0, 0, 0, 0, 0, 0 },
                    {  0, 0, 0, 0, 0, 0, 0, 0, 0, 0, 0, 0, 0, 0, 0, 0 },
                    {  0, 0, 0, 0, 0, 0, 0, 0, 0, 0, 0, 0, 0, 0, 0, 0 },
                    {  0, 0, 0, 0, 0, 0, 0, 0, 0, 0, 0, 0, 0, 0, 0, 0 },
                    {  0, 0, 0, 0, 0, 0, 0, 0, 0, 0, 0, 0, 0, 0, 0, 0 },
                    {  0, 0, 0, 0, 0, 0, 0, 0, 0, 0, 0, 0, 0, 0, 0, 0 },
                    {  0, 0, 0, 0, 0, 0, 0, 0, 0, 0, 0, 0, 0, 0, 0, 0 },
};
int bulletPosition[2] = {0,0};
int enBulletPosition1[4] = {0,0,0,0};
int enBulletPosition2[4] = {0,0,0,0};
int Enemys[6] = {random(0,3),random(0,3),random(0,3),random(0,3),random(0,3),random(0,3)};
/****************************************************************/
//Snake
/****************************************************************/

/****************************************************************/
//Space Invators
/****************************************************************/
const PROGMEM byte enemy1[2][2] = {
  {1,1},
  {1,1}};
const PROGMEM byte enemy2[2][1] = { 
  {1},
  {1}};

const PROGMEM byte block[4][4] = {
  {0,1,1,0},
  {1,1,1,1},
  {1,1,1,1},
  {0,1,1,0}};
const PROGMEM byte lod[2][3] = {
  {0,1,0},
  {1,1,1}};
  
const PROGMEM byte vybuch1[3][3] = {
  {1,1},
  {1,1}};  
const PROGMEM byte ship_explosion1[2][3] = {
  {0,0,0},
  {1,1,1}};
const PROGMEM byte ship_explosion2[2][3] = {
  {0,0,0},
  {1,0,1}};
/****************************************************************/
//Space Invators
/****************************************************************/

/****************************************************************/
//Menu
/****************************************************************/
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

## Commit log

2022-02-22 Create PCB_naming
2022-02-22 Update PCB_naming
    adding din
2022-08-25 Snaha o udelani interruptu
    Nakonec jsem zjistil ze to je hardwerova chyba
2022-09-18 Rename folder code to Firmware
    I renamed folder code to Firmware because it was similar as github button code
2022-10-27 Revert "Mistake-slower/bigger"
    This reverts commit 092e83d06186fa26a2ec9a688647ae0a62e0e741.
    [URXos.ino]
2022-10-28 1. Removed file PCB_naming it was not important. 2. Remaped battery indicator. 3. new Difficulty tab in settings.
2022-10-29 1. Changed Medium intensity 2. Repaired bug in galaxian - sound
    [URXos.ino]
2022-11-01 1. bug fixes 2. DanceMan modes
    [URXos.ino]
2022-11-04 1. Galaxian modes 2. New songs - Doom, Bloody tears 3. Bug fixes - high score menu
    [URXos.ino]
2022-11-07 1. New highscore celebration 2. sound bug fixes
    [URXos.ino]
2023-06-09 Schematics and pcb design
    [Urx.kicad_pcb, Urx.kicad_sch, tlacitka_urx.kicad_pcb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]
2023-06-11 Renaming and Hardware list
    [Components.xlsx, Urx.kicad_pcb, Urx.kicad_sch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]
2025-01-04 Version 0.8.3
    new button_pcb therefore the interrupt behaviour needs to be flipped
    [Urx.kicad_pcb, Urx.kicad_sch, tlacitka_urx.kicad_pcb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]
2025-01-15 New models
    [Urx_1_bot_v2.stl, Urx_1_bot_v4.stl, Urx_1_top_v1.stl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]
